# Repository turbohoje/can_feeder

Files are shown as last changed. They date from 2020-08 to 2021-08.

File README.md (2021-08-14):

# Wet Cat Food Feeder
Butters is a very special kitty, he can only keep wet food off the white duvets and furniture.  He cant seem to keep dry food down.

This is a bot to open wet cans by winching the lid off.

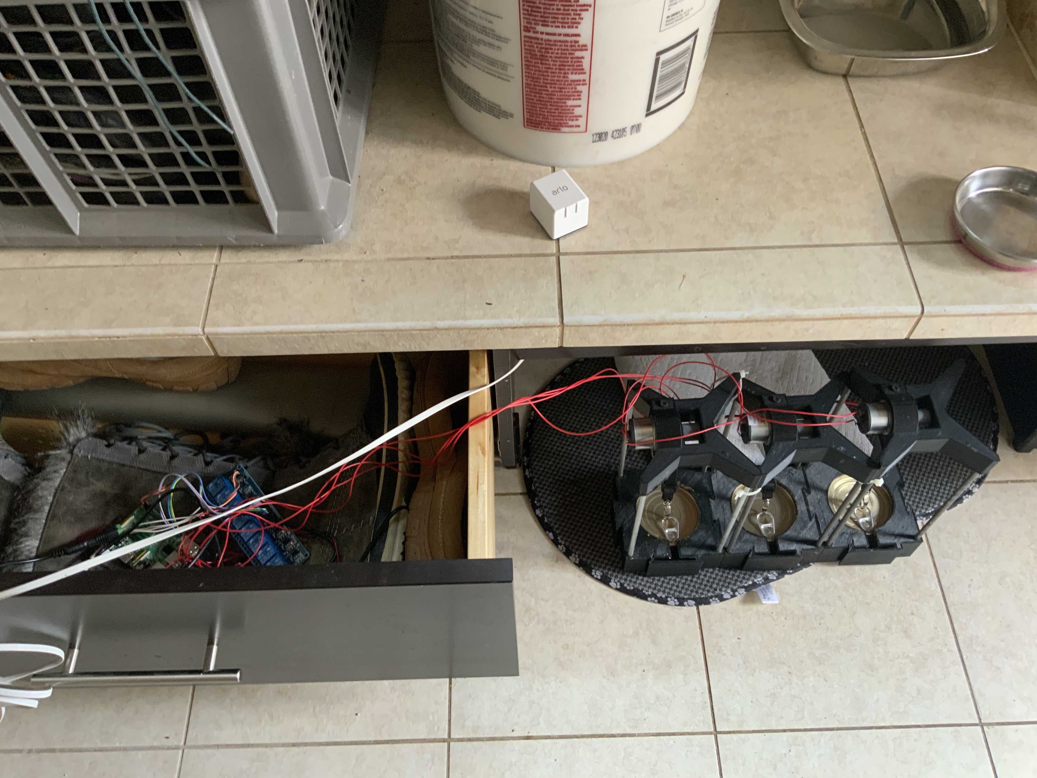
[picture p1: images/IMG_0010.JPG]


Zoomed view of the whole setup.  Arlo camera under the bench to watch the process.  The PI is wired to a block of relays and a manual mechanical H-bridge is wired to allow for an easy reverse stage as well.

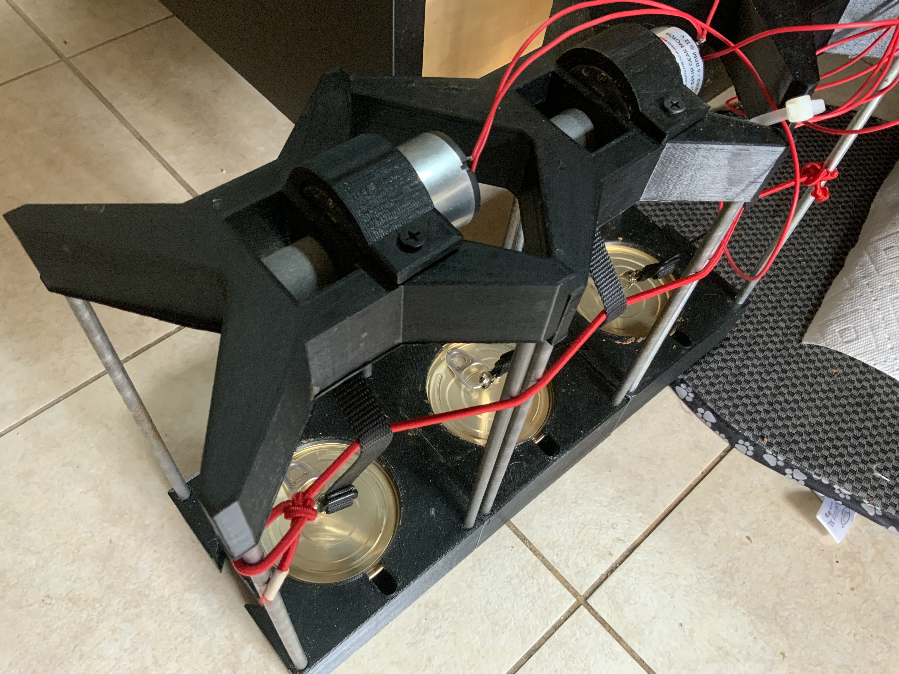
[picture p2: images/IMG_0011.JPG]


cascade of 3 units.  PLA was not strong enough for the winch hub, had 3 of the gray pieces made at shapeways to prevent the shaft from stripping out the winch hub which happened after about 10 cycles. 

## Raspberry Pi

Running on a pi3, with pios lite https://www.raspberrypi.org/downloads/raspberry-pi-os/

How to get this server on its feet:
Get on the host with a keyboard and screen, expand filesystem, enable ssh server.
```
apt-get install python3-pip
pip3 install RPi.GPIO git zsh
git clone git@github.com:turbohoje/can_feeder.git
```

## OpenSCAD Models
Below are the models in this project

This base below will cascade hook to other bases.

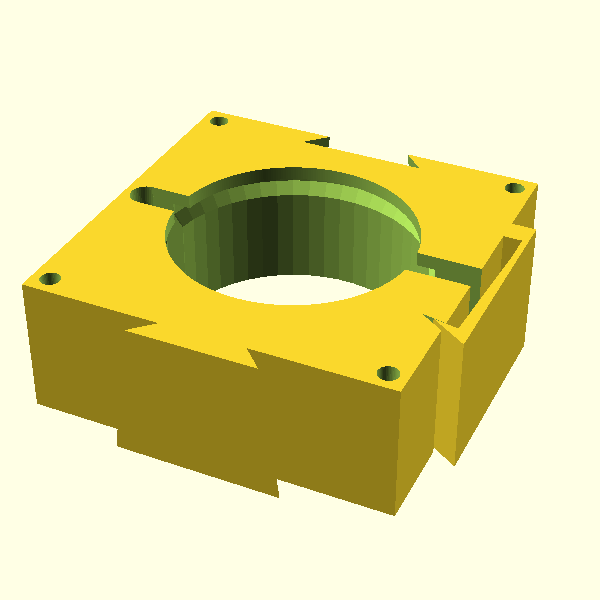
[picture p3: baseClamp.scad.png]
base


The base and the top are joined with .25" rod (x4).

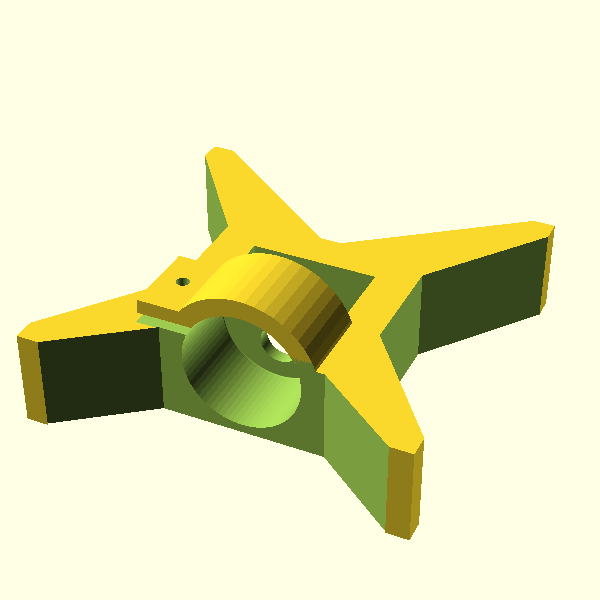
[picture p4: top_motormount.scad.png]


#### The following are supplemental models

Prototype winch.

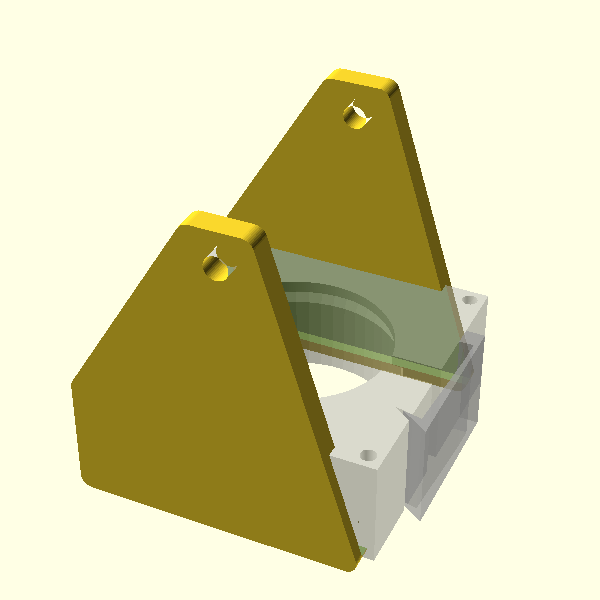
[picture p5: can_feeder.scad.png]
prototype


This is a gear motor from sparkfun.  This is subtracted from the material above.

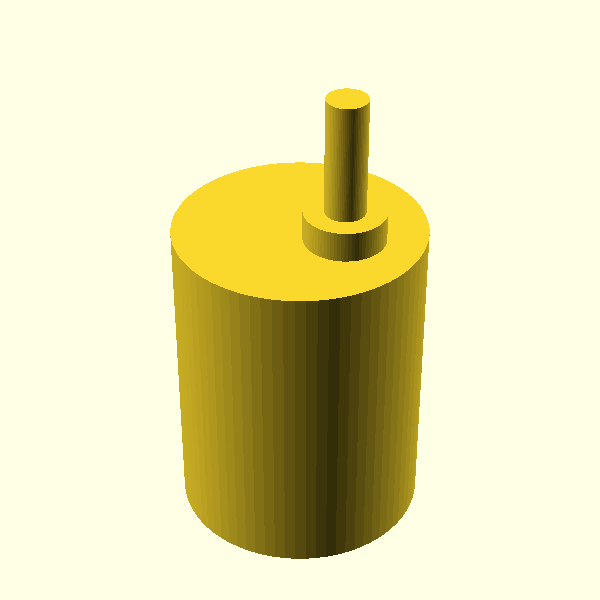
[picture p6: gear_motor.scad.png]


This is the spool that goes on the motor.  1/2" nylon strap wraps up around ths.

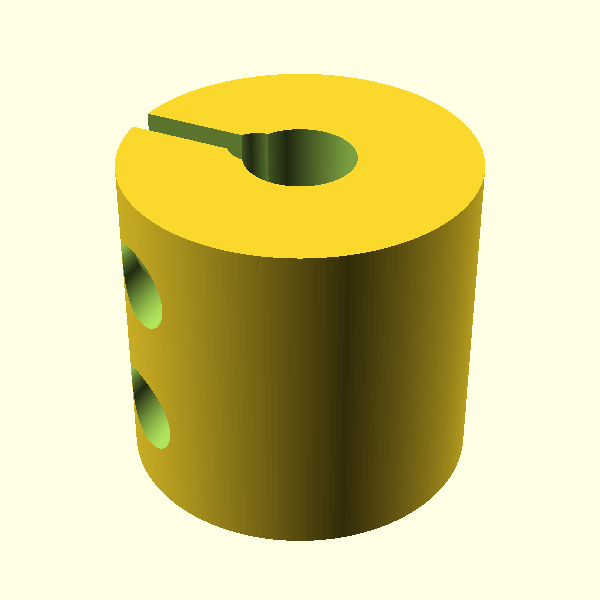
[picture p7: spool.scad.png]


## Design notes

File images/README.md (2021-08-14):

# Images of working project





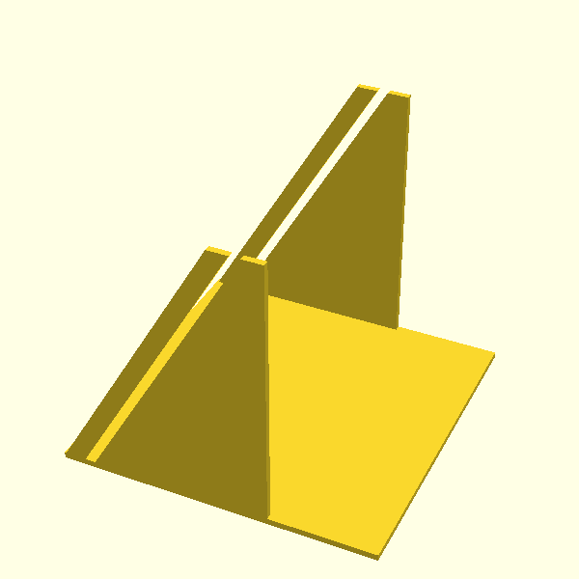
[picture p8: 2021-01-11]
breadCutter.scad.png

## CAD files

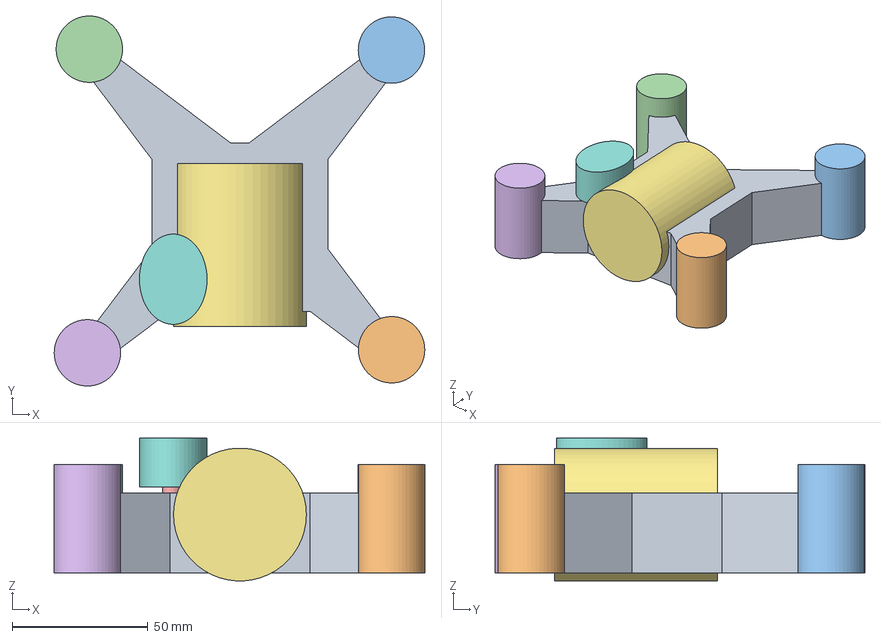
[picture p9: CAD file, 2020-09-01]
PI3_top_motormount.3mf
136.7 x 136.5 x 52.6 mm
top_motormount.stl
infill.stl(1)
infill.stl(2)
infill.stl(3)
infill.stl(4)
infill.stl(6)
infill.stl(5)
infill.stl

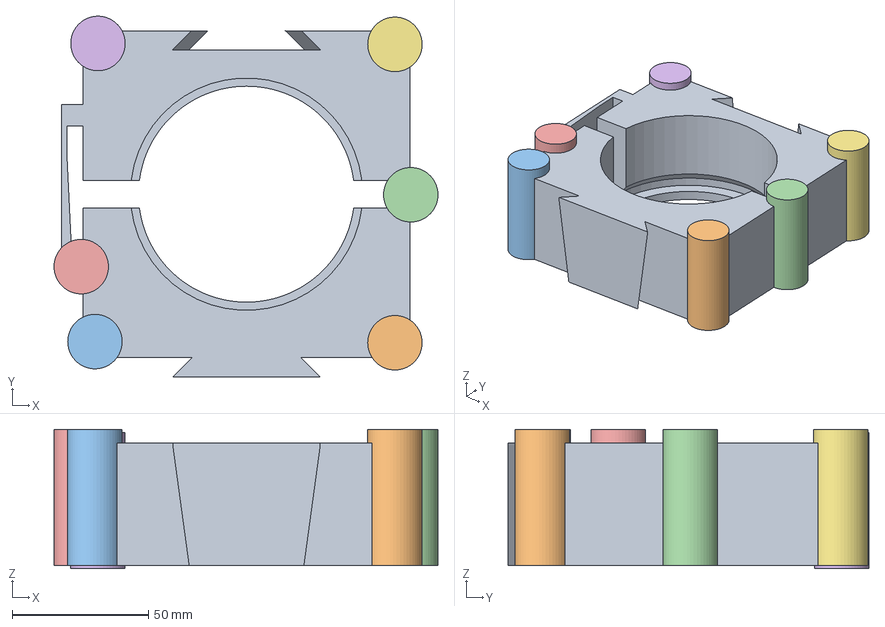
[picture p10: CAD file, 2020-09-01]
PI3_can_feeder_base_cura.3mf
141.1 x 132.4 x 51.2 mm
baseClamp.stl
infill.stl
infill.stl(1)
infill.stl(2)
infill.stl(3)
infill.stl(4)
infill.stl(5)

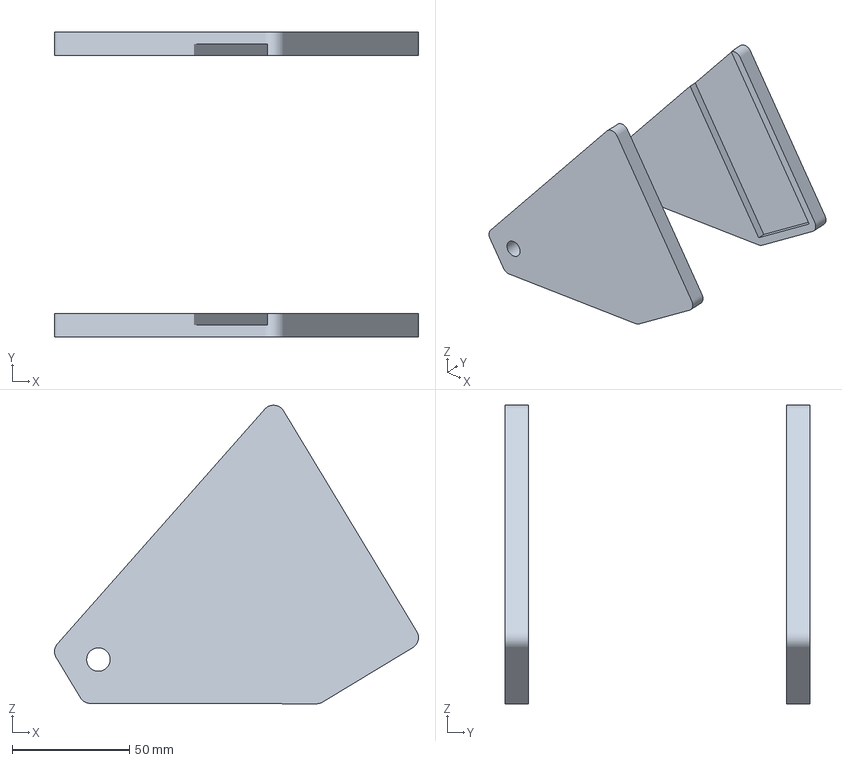
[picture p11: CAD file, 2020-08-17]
PI3_risers.3mf
155.3 x 130.0 x 127.4 mm

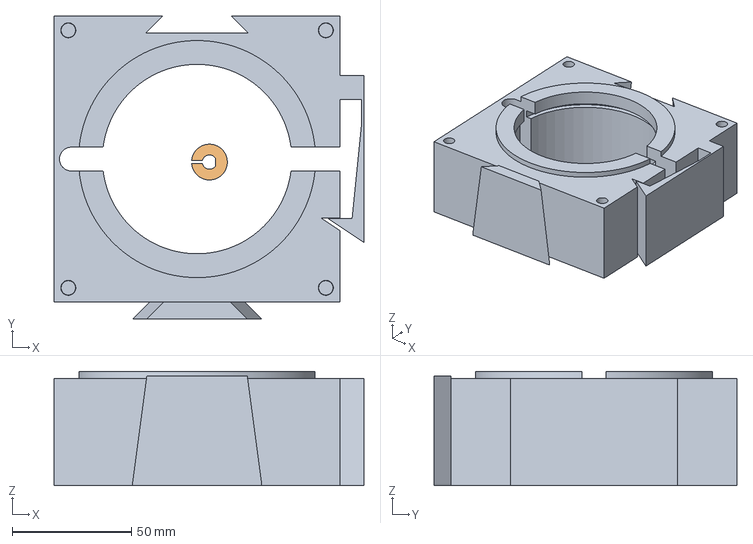
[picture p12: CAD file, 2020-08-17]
PI3_baseClamp2.3mf
130.0 x 127.1 x 48.0 mm
baseClamp2.stl
spool.stl

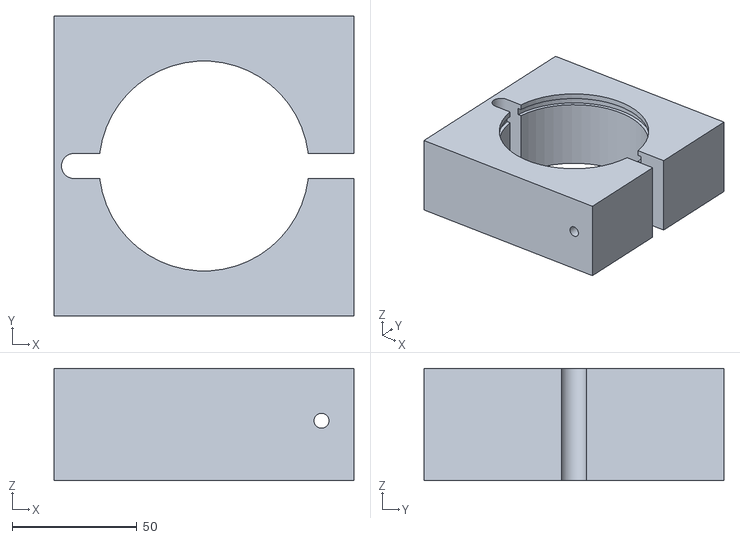
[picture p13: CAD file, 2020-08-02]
can_feeder.stl
120.0 x 120.0 x 45.0

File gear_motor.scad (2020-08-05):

$fn=75;

module motor(){
    gearboxDia   = 37/2;
    gearboxDepth = 24.5;
    motorDia     = gearboxDia;//33/2;
    motorDepth   = 23;
    depth        = gearboxDepth + motorDepth;
    shaftBearing = 12/2;
    shaftBheight = 4.5;
    shaftDia     = 6/2;
    shaftLen     = 22;
    shaftOffset  = 10 - shaftDia;
    
    //gearbox
    linear_extrude(gearboxDepth)
        circle(gearboxDia);
    
    //motor
    translate([0,0,-motorDepth+.01])
    linear_extrude(motorDepth)
        circle(motorDia);
    
    //shaft bearing
    translate([shaftOffset,0,0+gearboxDepth])
    linear_extrude(shaftBheight)
        circle(shaftBearing);
    
    //shaft
    translate([shaftOffset,0,0+gearboxDepth])
    linear_extrude(shaftLen)
        circle(shaftDia);
}

motor();

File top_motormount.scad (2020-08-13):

$fn = 50;


$baseWidth = 120;
$baseDepth = $baseWidth;
$clampHeight = 45;
$canRadius = 42.5;
$canLip = 2;

use <baseClamp.scad>;
use <gear_motor.scad>;

$lidHeight = 30;
module topMotorMount(){
	difference(){
		union(){
			cube([$baseWidth,$baseDepth,$lidHeight], center=true);
			
			//clamp
			translate([0,-27,7])
				rotate([90,0,0])
				cylinder(25, 6+37/2, 6+37/2, center=true);
			translate([-20,-27,10])
			cube([25,25,25], center=true);
		}
		
		//clampCuts
		translate([-20,-27,16.5])
			cube([26,26,3], center=true);
		translate([-25,-26,20])
			rotate([0,0,0])
			cylinder(15, 1, 1, center=true);
		translate([-25,-26,22])
			rotate([0,0,0])
			cylinder(11, 2, 2, center=true);
		
		//peg holes, slight taper for captivity 6.35/2 is .25"
		xy_radius = $baseWidth/2-6;
		for($x = [-1,1]){
			for($y = [-1,1]){
			translate([$x*xy_radius, $y*xy_radius, -$lidHeight/4 ])
				cylinder($lidHeight*(.8), 6.6/2, 6/2, center=true);
			translate([$x*xy_radius, $y*xy_radius, -$lidHeight/4 + $lidHeight/2-2])	
				cylinder(2, 6/2, 0, center=true);
				
			}
		}
		
		//center cutout
		translate([0,0,-2])
		cube([40, 20, $lidHeight +5], center=true);
		
		//motor cut
		minkowski(){
			translate([0,21-$baseWidth/2,7]){
				rotate([0,90,90])
				motor();
			}
			sphere(.25);
		}
		
		//reliefs
		relief(55);
		rotate([0,0,180])
			relief(55);
		rotate([0,0,-90])
			relief(75);
		rotate([0,0,90])
			relief();
	
		//cut bottom off clamp
		translate([0,0,-$clampHeight/2-2])
			cube([$baseWidth,$baseDepth,20], center=true);
	}
}

module relief(innersq = 41){
	inset = 3;
	
	translate([0,0,-($lidHeight+5)/2])
	linear_extrude($lidHeight+5){
		difference(){
			polygon(points=[
				[-$baseWidth/2-inset, -$baseDepth/2+inset],
				[-$baseWidth/2-inset, $baseDepth/2-inset],
				[-20,0]
			]);
			square([$baseWidth-innersq,$baseDepth-innersq], center=true);
		}
	}
}


topMotorMount();


//%translate([0,0,-100])
//baseClamp();

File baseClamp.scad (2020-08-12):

$fn=50;



module baseClamp(){
    union(){
        lipSize =3;
        difference(){
            union(){
                cube([$baseWidth,$baseDepth,45], center=true);
                
                //top lip
                //translate([0,0,45/2])
                //linear_extrude(3)
                //    circle($canRadius-lipSize+10, $fn=500);
                
            }
            
            //can
                //can
			translate([0,0,-8])
			 cylinder(50,$canRadius, $canRadius, center=true);
			//lip
			translate([0,0,16])
				cylinder(4,$canRadius+$canLip, $canRadius+$canLip, center=true);
			//smaller top lip
			cylinder(60,$canRadius-lipSize, $canRadius-lipSize, $fn=300, center=true);
			//printing upside down, dont want to scaffold, this cone is for cleanlyness
			translate([0,0,12.01])
				cylinder(4,$canRadius, $canRadius+$canLip, center=true);
            
            //clamp cuts
            translate([($baseWidth/2), 0, -1])
                cube([($baseWidth/2)+10, 10, ($baseWidth/2)], center=true);
            //hinge
            translate([($baseWidth/4)-$canRadius-10, 0, -1])
                union(){    
                    cube([($baseWidth/2), 10, ($baseWidth/2)], center=true);
                    hull(){
                        translate([-($baseWidth/4), 0, 45])
                            sphere(d=10);
                        translate([-($baseWidth/4), 0, -45])
                            sphere(d=10);
                    }
                }
                //}
            
            //bolt
//            translate([$baseWidth/2+12, 0, 0])
//                rotate([90,0,0])
//                    cylinder($baseDepth+20, 3, 3, center=true);
                
            //peg holes, slight taper for captivity 6.35/2 is .25"
            xy_radius = $baseWidth/2-6;
            for($x = [-1,1]){
                for($y = [-1,1]){
                translate([$x*xy_radius, $y*xy_radius, 12])
                    cylinder(45, 6/2, 6.6/2, center=true);
				#translate([$x*xy_radius, $y*xy_radius, -11.5])	
					cylinder(2, 0, 6/2, center=true);
                }
            }
			
			//cutaway for snap
			standoff=5;
			yattach=25;
            
			tighten = -1;
			innes	= 3;
			
			translate([0,0,-45/2-.5])
			linear_extrude(46)
				polygon(points=[
					[$baseWidth/2+standoff-innes, -yattach-tighten-2],
					[$baseWidth/2-standoff-innes, -yattach-tighten],
					[$baseWidth/2+2*standoff-innes, -yattach-(2*standoff)-tighten],
				]);
        }
		
		//add the snap
		standoff=4;
		yattach=25;
		
		translate([0,0,-45/2])
		linear_extrude(45){
			polygon(points=[
				[$baseWidth/2, yattach],
				//thin part
				[$baseWidth/2+standoff + (standoff/2), yattach],
				[$baseWidth/2+standoff + (standoff/2), yattach-10],
			
				[$baseWidth/2+standoff, -yattach-1.5],
				[$baseWidth/2-standoff, -yattach],
				[$baseWidth/2+2*standoff, -yattach-(2*standoff)],
				[$baseWidth/2+2*standoff, yattach+standoff*2],
				[$baseWidth/2, yattach+ 2*standoff],
		
			]);
		}
		
		
    }
}

module defaults(){
    
    $baseWidth = 120;
    $baseDepth = $baseWidth;
    $clampHeight = 45;

    $canRadius = 42.65;
	$canLip = 3;  
        
    difference(){
		baseClamp();
		
		translate([0,$baseWidth/2+.1, 0])
			rotate([0,0,180])
				scale([1.01,1.01,1.01])
				cleat();
	}
		
	translate([0,-$baseWidth/2, 0])
		rotate([0,0,180])
			cleat();
}

module cleat(){
	cleatThickness 	= 10;
	cleatAngle		= 45;
	cleatWidth		= 20;
	cleatHeight		= 45;
	shrink			= .7;
	
	translate([0,0,-cleatHeight/2])
		hull(){
			linear_extrude(1) //tricks hull
			polygon(points=[
				[cleatWidth, 0],
				[cleatWidth + cleatThickness * sin(cleatAngle), cleatThickness * cos(cleatAngle)],
				[-cleatWidth - cleatThickness * sin(cleatAngle), cleatThickness * cos(cleatAngle)],
				[-cleatWidth, 0],
		
			]);
			translate([0,0,cleatHeight])
			linear_extrude(.001)
			polygon(points=[
				[shrink*cleatWidth, 0],
				[shrink*cleatWidth + cleatThickness * sin(cleatAngle), cleatThickness * cos(cleatAngle)],
				[shrink*-cleatWidth - cleatThickness * sin(cleatAngle), cleatThickness * cos(cleatAngle)],
				[shrink*-cleatWidth, 0],
		
			]);
		}
		
}


defaults();

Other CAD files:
can_feeder_base_cura.3mf
can_feeder.scad
spool.scad

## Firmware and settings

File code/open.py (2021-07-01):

#!/usr/bin/env python3

import RPi.GPIO as GPIO
import time
import sys, getopt

# GPIOid - rpi-PIN
# 16 - 36
# 20 - 38
# 21 - 40


#for p in [36, 38, 40] :

feeder = None
seconds = None

def err(str):
    print(str)
    exit(2)

try:
    opts, args = getopt.getopt(sys.argv[1:],"f:s:",["feeder=","seconds="])
except getopt.GetoptError:
    err(__file__ + ' -f <feeder> -s <seconds> | --feeder=<feeder> --seconds=<seconds>')
for opt, arg in opts:
    if opt in ['-f', '--feeder', '--feeder=']:
        try:
            feeder = [0,36,38,40][int(arg)]
        except:
            err(__file__ + ' -f <feeder> -s <seconds> | --feeder=<feeder> --seconds=<seconds>')
    elif opt in ['-s', '--seconds', '--seconds=']:
        seconds = int(arg)
if(feeder == None or seconds == None):
    err(__file__ + ' -f <feeder> -s <seconds> | --feeder=<feeder> --seconds=<seconds>')

p=feeder

GPIO.setmode(GPIO.BOARD)
GPIO.setup(p,GPIO.OUT)
GPIO.output(p,GPIO.LOW)
time.sleep(seconds)
GPIO.output(p,GPIO.HIGH)

GPIO.cleanup()

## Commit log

2020-08-02 test print of clamp
    [can_feeder.scad, can_feeder.stl, can_feeder_base_cura.3mf]
2020-08-02 ext module for clamp and a frame sides
    [baseClamp.scad, can_feeder.scad]
2020-08-03 different angle, retry
    [can_feeder.scad]
2020-08-04 modulization, scoping, base upgrades for posts
    [baseClamp.scad, can_feeder.scad]
2020-08-04 gear motor from sparkfun
    [gear_motor.scad]
2020-08-04 first shot at an engine spool
    [spool.scad]
2020-08-04 added more meat to top lip
    [baseClamp.scad]
2020-08-04 snap improvements, puzzle pieces
    [baseClamp.scad]
2020-08-05 top mount 1.0, modded motor to make cut easy
    [baseClamp.scad, gear_motor.scad, spool.scad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]
2020-08-05 removed unecc material
    [top_motormount.scad]
2020-08-05 spool updates after print failures
    [spool.scad]
2020-08-12 misc upgrades
    [baseClamp.scad, spool.scad, top_motormount.scad]
2020-08-13 changes to lid for more spool room
    [top_motormount.scad]
2020-08-17 adding cura files for a reference
    [PI3_baseClamp2.3mf, PI3_can_feeder_base_cura.3mf, PI3_risers.3mf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]
2020-08-17 small changes
    [PI3_top_motormount.3mf]
2020-08-20 updates to cura infills, strap has flaws but acceptable
    [PI3_top_motormount.3mf]
2020-08-20 more fixes to cura
    [PI3_top_motormount.3mf]
2020-09-01 changes in cura
    [PI3_can_feeder_base_cura.3mf, PI3_top_motormount.3mf]
2021-07-01 updates to spool
    [spool.scad]
